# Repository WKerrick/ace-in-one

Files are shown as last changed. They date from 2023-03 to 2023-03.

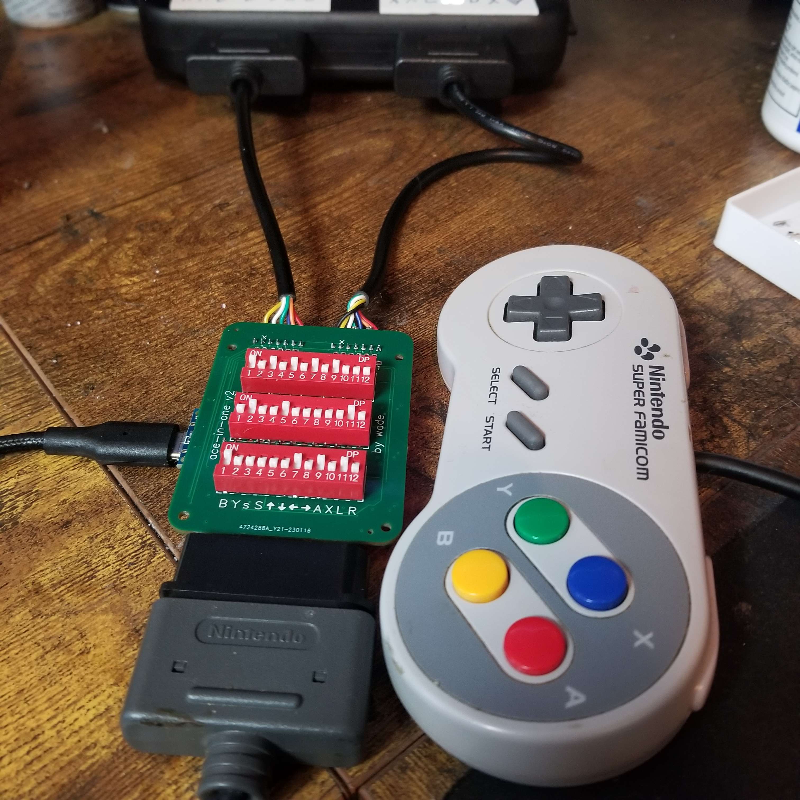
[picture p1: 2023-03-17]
Images/Assembled Image.jpg

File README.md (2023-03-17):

# The Ace-in-One
The purpose of this project is to make an alternative to acquiring the 2 multitaps and additional controllers needed for ACE speedruns like 0 Exit in Super Mario World. This device mimics having multitaps plugged into both port 1 and 2, with a controller in the first two ports of each multitap. Instead of using clamps and other items to hold down buttons on the additonal controllers, DIP switches are used instead.

## Production
You can use the Gerber, BOM, and Pick-n-Place files to have a PCB manufacturer build the board for you. I personally use JLCPCB, but there are many boardhouses out there for you to choose from.

## Addtional Items
* 1 SNES Controller Connector (female)
* 3 DIP Switches (12P)
* 2 Output Connectors (options described below)
* Output Cables (24awg6c or 26awg7c)
* 2 SNES Controller Connectors (male)
* 1 Arduino Nano (optional)

## Output Connectors
The Ace-in-One can 3 different styles of connector you can use for output. Make sure you have the required hardware for your output of choice, including any crimpers that are needed.

1. 0.1" 6P (for headers or standard auto connectors)
2. 2mm 6P (for JST_PH connectors)
3. 2mm 7P (in case you're like me and have 7P cables pre-made for other devices)

## Pinouts
### Arduino Nano
 Pin | Name
---- | ----
6 | Clock
3 | Latch
4 | Data1

### Output Port 1
 Pin | Name
---- | ----
1 | 5v
2 | Clock
3 | Latch
4 | Data1
5 | Data2
6 | [UNUSED]
7 | Ground

### Output Port 2
 Pin | Name
---- | ----
1 | 5v
2 | Clock
3 | Latch
4 | Data3
5 | Data4
6 | [UNUSED]
7 | Ground

## Notes
If adding Arduino, make sure to solder the middle DIP first, followed by the arduino, and then the other 2 DIP switches— otherwise it'll be a tight squeeze.

Any questions or comments can be sent to discord (WKerrick#0258) or twitter (w_kerrick)

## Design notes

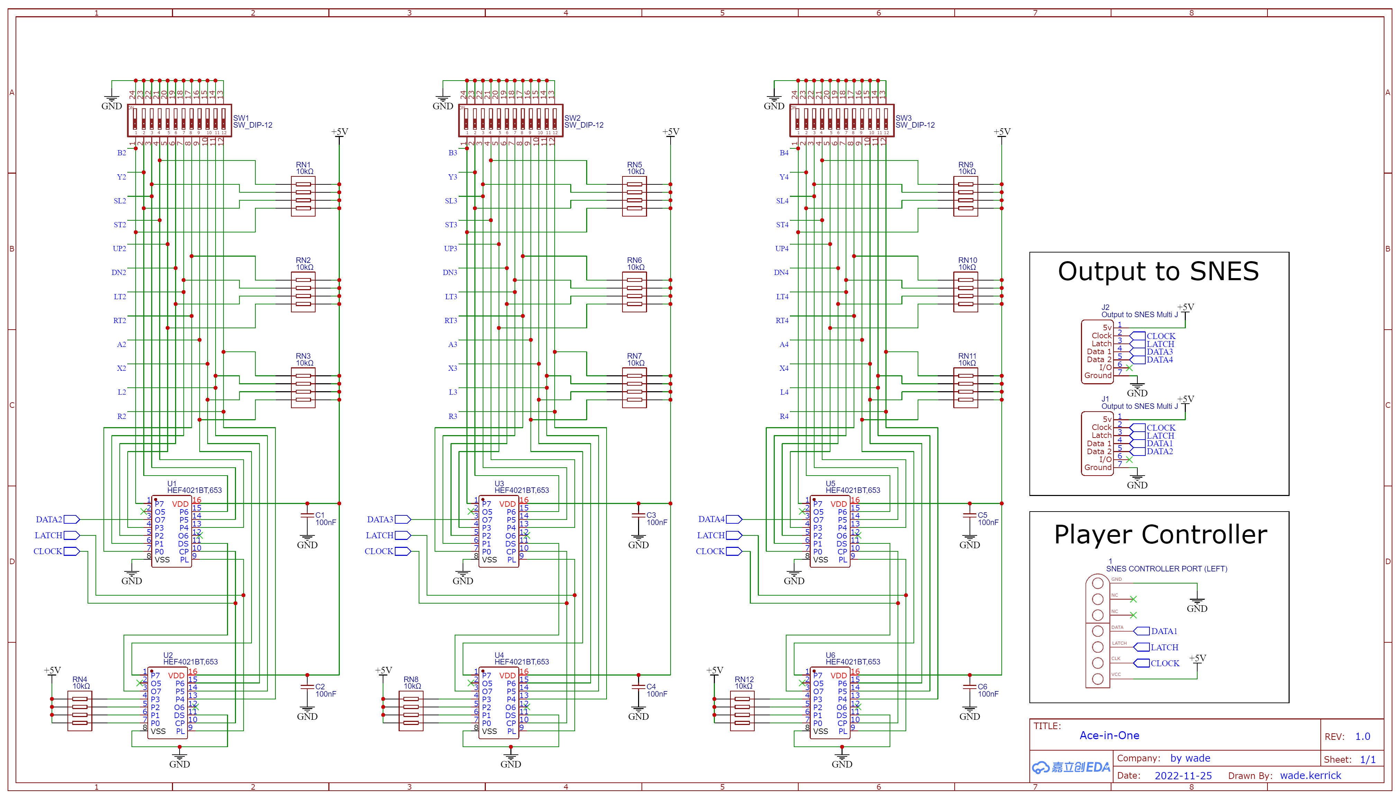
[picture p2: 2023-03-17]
Schematic/ACE-IN-ONE v1.png

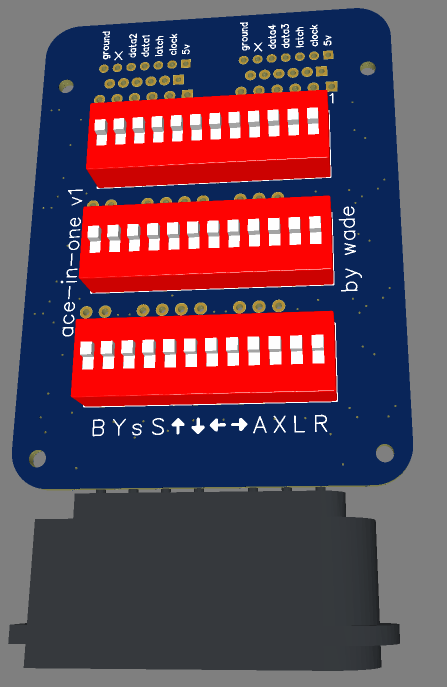
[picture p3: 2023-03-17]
Images/Model Image.png

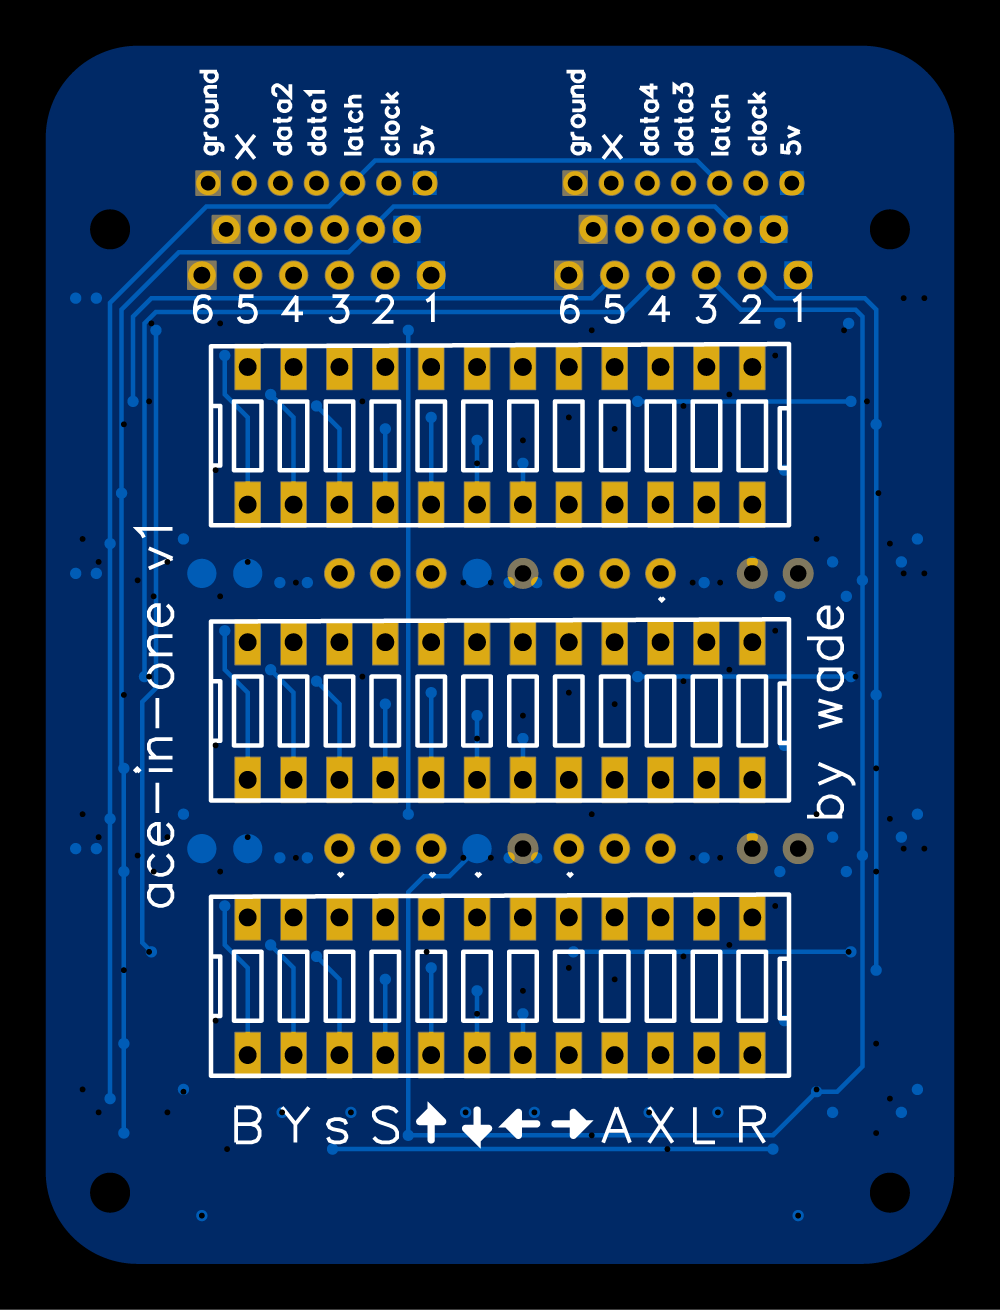
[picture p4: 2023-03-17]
Images/PCB_bottom.png

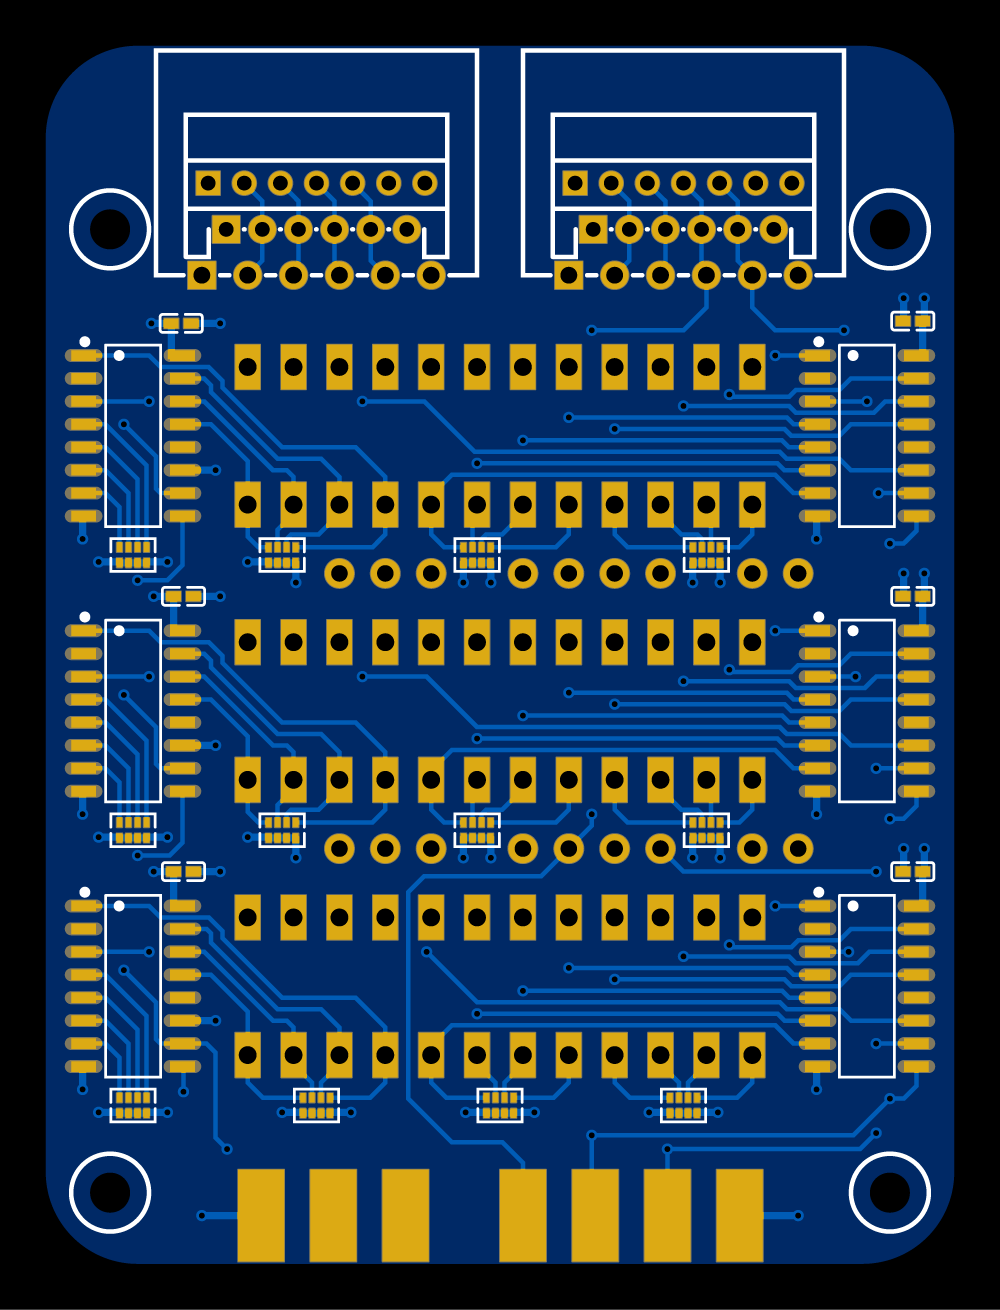
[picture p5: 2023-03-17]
Images/PCB_top.png

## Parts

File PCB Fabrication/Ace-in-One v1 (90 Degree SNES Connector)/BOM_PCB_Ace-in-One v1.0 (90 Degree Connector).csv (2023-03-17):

ID | Name | Designator | Footprint | Quantity | Manufacturer Part | Manufacturer | Supplier | Supplier Part | Price
1 | SW_DIP-12 | SW1,SW2,SW3 | DIPSWITCH-12 | 3
2 | HEF4021BT,653 | U1,U2,U3,U4,U5,U6 | SOIC-16_L9.9-W3.9-P1.27-LS6.0-BL | 6 | HEF4021BT,653 | Nexperia | LCSC | C6729 | 0.054
3 | SNES CONTROLLER PORT (LEFT) | 1 | SNES CONNECTOR (LEFT) | 1
4 | 100nF | C1,C2,C3,C4,C5,C6 | C0402_NEW | 6 | CL05B104KO5NNNC | SAMSUNG(三星) | LCSC | C1525
5 | Output to SNES Multi J | J1,J2 | SNES OUTPUT MULTI J | 2
6 | 10kΩ | RN1,RN2,RN3,RN4,RN5,RN6,RN7,RN8,RN9,RN10,RN11,RN12 | RES-ARRAY-SMD_0402-8P-L2.0-W1.0-BL | 12 | 4D02WGJ0103TCE | UniOhm | LCSC | C25725 | 0.001

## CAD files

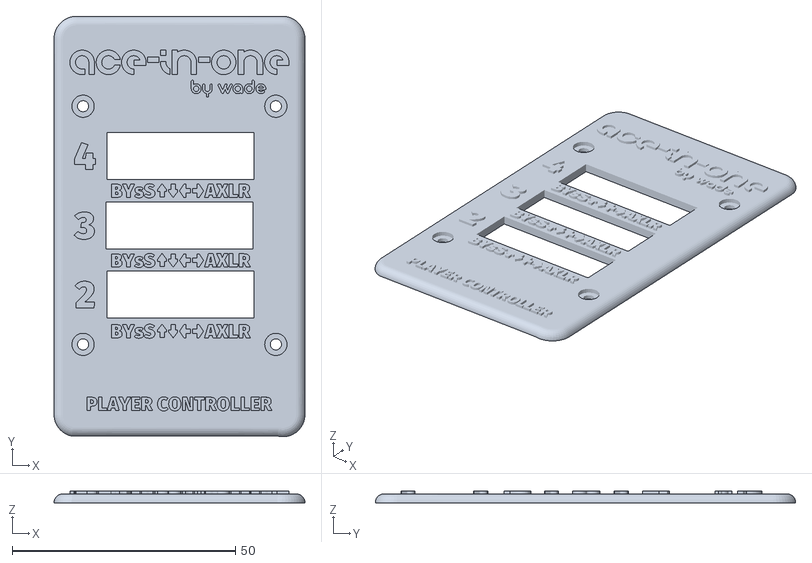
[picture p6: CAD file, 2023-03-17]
Enclosure/Ace-in-One Enclosure Faceplate.stl
56.2 x 94.2 x 2.60

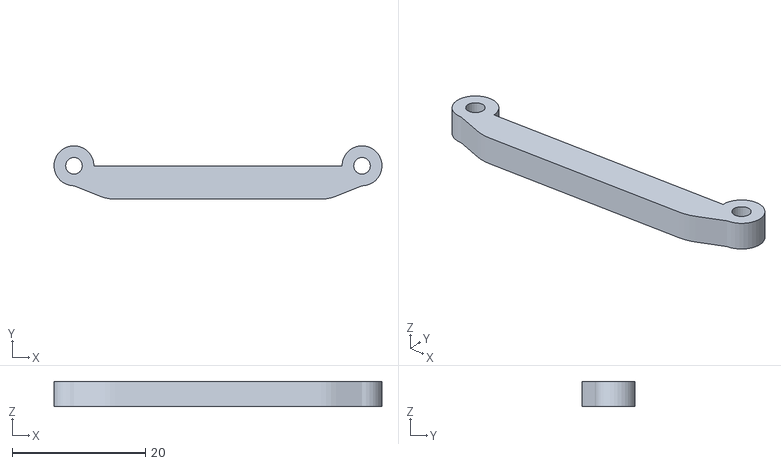
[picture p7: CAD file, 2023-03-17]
Enclosure/Ace-in-One Enclosure Rear Support.stl
49.2 x 7.99 x 3.80

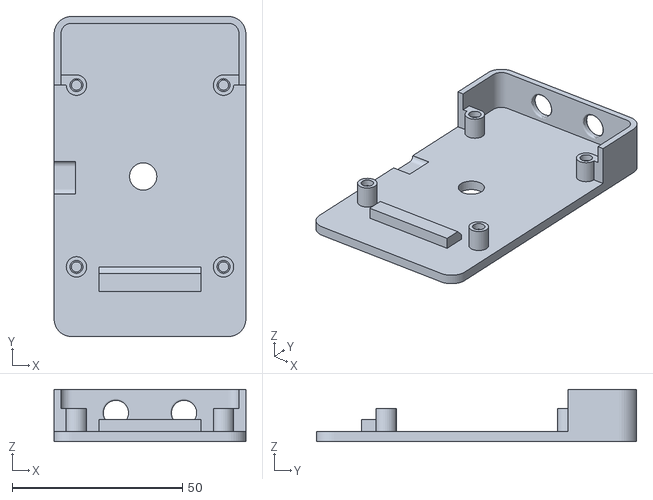
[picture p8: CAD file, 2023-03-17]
Enclosure/Ace-in-One Enclosure Body.stl
56.3 x 93.9 x 15.3

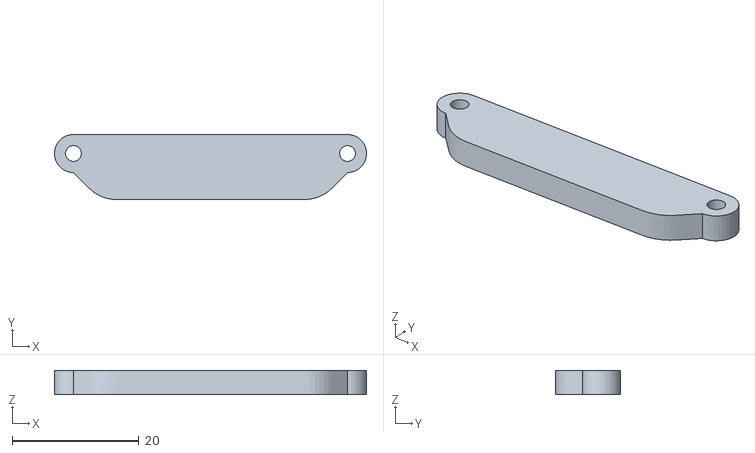
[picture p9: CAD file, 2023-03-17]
Enclosure/Ace-in-One Enclosure Front Support.stl
49.2 x 10.2 x 3.80

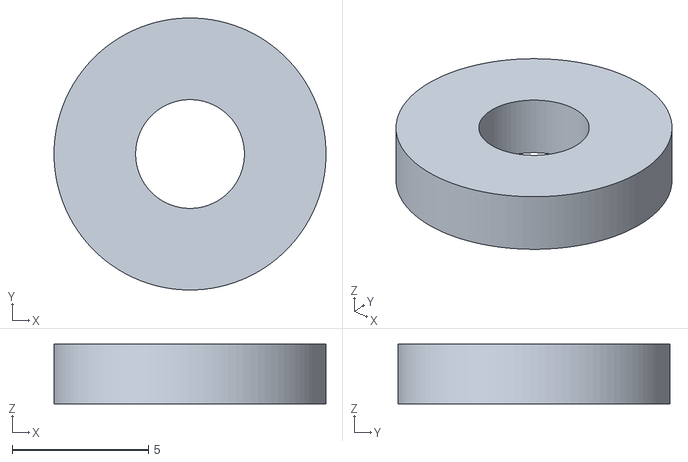
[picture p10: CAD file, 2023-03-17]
Enclosure/2.2mm Stack.stl
10.00 x 10.00 x 2.20

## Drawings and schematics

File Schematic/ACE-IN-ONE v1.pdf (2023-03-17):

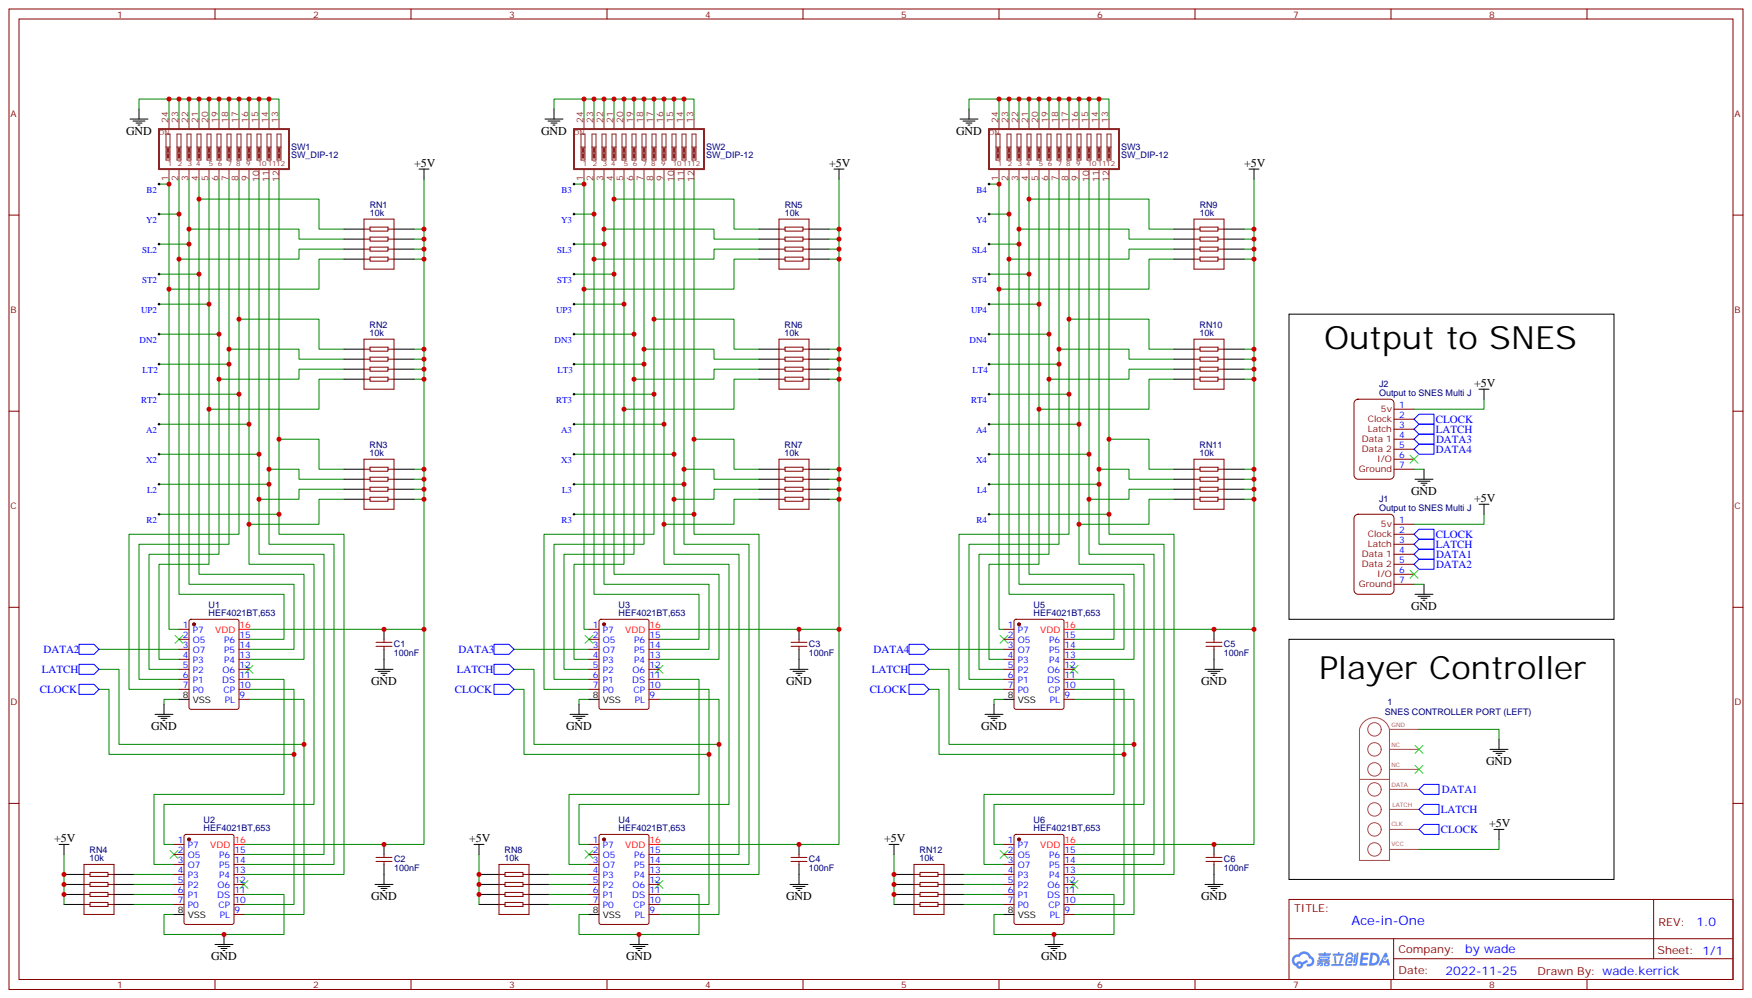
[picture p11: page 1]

SNES CONTROLLER PORT (LEFT)

Drawn By: wade.kerrick

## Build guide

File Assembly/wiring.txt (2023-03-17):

red    : 5v
orange : clock
green  : latch
white  : data1
yellow : data2
blue   : io
black  : ground
